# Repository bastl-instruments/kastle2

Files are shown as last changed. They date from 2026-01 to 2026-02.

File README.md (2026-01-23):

# Kastle 2

*Compatible with [Bastl Instruments Citadel](https://github.com/bastl-instruments/citadel)*

A modular DSP platform that fits into your pocket!  
Comes with open-source codebase (including two official firmwares) and schematics.

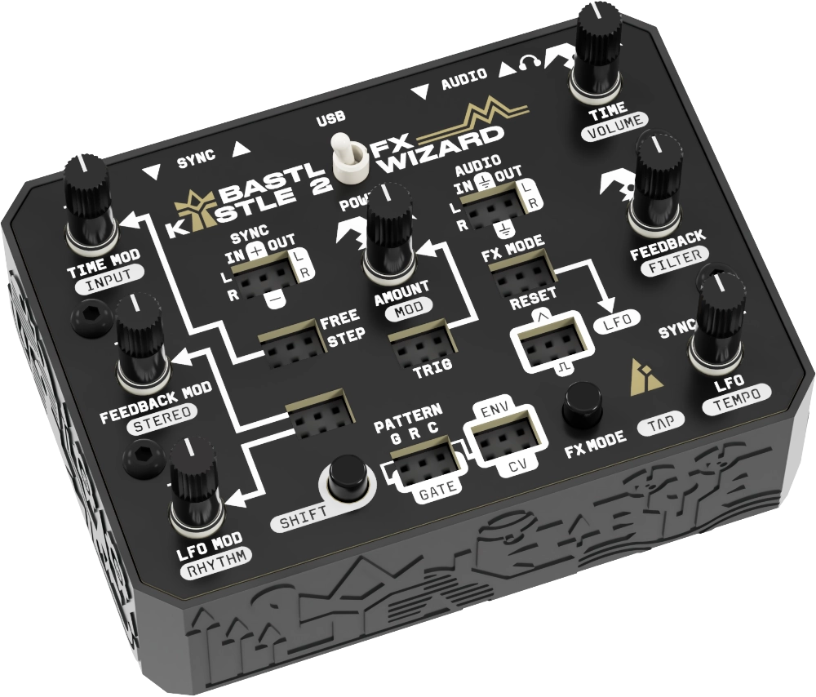
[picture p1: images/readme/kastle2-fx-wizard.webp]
Kastle 2
 

## How to develop for Kastle 2

Read [Toolchain Install Guide](TOOLCHAIN_INSTALL.md), [Coding Style Guide](CODING_STYLE.md) and [Glossary & Examples](GLOSSARY_EXAMPLES.md), or dive through the generated [Code Documentation](http://apps.bastl-instruments.com/kastle2-docs).
 
Any questions or weird stuff hapenning? See the [FAQ](FAQ.md) or discuss your experience on our [Discord server](https://discord.com/invite/C4RXRjgYJ6). 

## Specifications

- Raspberry Pi RP2040 MCU (264 kB RAM, clocked at 176 MHz)
- 8 MB flash for firmware and data
- 256 B EEPROM for storing calibration and settings
- 44kHz/16-bit stereo audio quality
- USB-C or 3xAA battery power (with automatic switching)
- 18 analog inputs (12-bit)
  - 2 direct inputs (sample rate > 1 kHz)
  - 16 multiplexed inputs (sample rate > 100 Hz)
- 3 digital inputs
- 3 analog outputs (using filtered 10-bit PWM)
- 3 digital outputs
- Stereo audio input (up to 6 Vpp)
- Stereo headphone output (suitable for up to 250 Ohm headphones)
- 3 RGB LEDs
- USB MIDI input & output - see the [MIDI Mappings](MIDI_MAPPINGS.md)

All inputs are designed to accept voltages in the range of 0-5V unless specified.  
All outputs are designed to provide 0-5V (0V to the input voltage, respectively).

## Connectivity
- USB-C (power, firmware updates, MIDI)
- Sync in jack (expects a clock signal at tip)
- Sync out jack (produces a clock signal at tip)
- Audio in jack
- Headphone out jack

## User interface
- 7 potentiometers
- 2 buttons
- Pin headers for patching
- Power switch

## Power consumption, battery life

Power consumption is approximately 100-150 mA, allowing for up to 15-18 hours of use on 3xAA batteries.

## Open Source Firmwares

The full firmware list is here: [app list](APP_LIST.md).

**FX Wizard**   
Nine time-based audio effects, with DJ-style lowpass/highpass filter.

**Wave Bard**   
Stereo sample player featuring unique sequencing techniques.

And other examples, see the `code/src/apps` subfolder.

## Useful links

**[Citadel repository](https://github.com/bastl-instruments/citadel)**  
A Eurorack adaptation of the Kastle 2 family. It's directly compatible with the Kastle 2 firmwares, there are no extra Citadel firmware builds. The firmware itself detects the variant it's running on (based on the MIDI pull-up resistor on RX line) and adjusts necessary parameters.

**[Kastle 2 Web Apps repository](https://github.com/bastl-instruments/kastle2-webapps)**  
Source codes for Wave Bard Sample Loader, Alchemist Laboratory…

**[Kastle 2 Label Maker repository](https://github.com/bastl-instruments/kastle2-labelmaker)**  
Source code for a tool which helps you visualize Kastle 2 app ideas.

## Credits

**Developed by**   
Václav Mach ([@xx0x](https://github.com/xx0x)), Marek Mach ([@machmar](https://github.com/machmar))

**Supervised by**  
Václav Peloušek ([@vaclav-bastl](https://github.com/vaclav-bastl)), Martin Klecl ([@martinklecl](https://github.com/martinklecl))

Thanks to Majkel ([@tenmajkl](https://github.com/tenmajkl)) with help around documentation and everyone at Bastl Instruments for their support while working on this!

## License

**Code**  
MIT license

**Schematics, Documentation, Templates, Printable 3D files**  
CC BY SA 4.0 license

**Voice recordings (Version, Calibration, Test Mode)**  
CC0 license, made using TTS Maker (voice 178 - Chloe) and sped up by 1.05x

**Panel graphics, Case artwork**  
All rights reserved

**Samples (eg. Wave Bard factory bank)**  
All rights reserved

*Note: You are welcome to create derived products based on the schematics and software. However, Bastl retains proprietary rights to the board layout, which is not publicly available. This prevents simple product cloning and maintains the integrity of the original Kastle 2. By purchasing an original Bastl Instruments Kastle 2 you support ongoing development.*

*Regarding samples: The SAMPLES.BIN file in the repository should not be commercially distributed as part of a custom-built firmware, nor separately, as it is marked “All rights reserved.” However, using the official compiled firmware provided by Bastl (which includes the samples) is fine.*

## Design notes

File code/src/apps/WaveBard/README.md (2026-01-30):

# Kastle 2 Wave Bard

Sample player firmware for the Kastle 2 platform. Has three main parameters: Sample, Pitch and Length.  
Bank button switches between banks.   
By default there are 6 banks of 8 samples.

## How to build

Running `make wave-bard` produces a firmware image with just the app itself—ideal for development or upgrade process.

Running `make wave-bard-with-samples` builds the app and appends the data from SAMPLES.bin, creating the complete firmware. That's the way the official firmwares are generated.

## Wave Bard Sample Format

The samples, scales and rhythms are packed in a special format. You can find the specs in the [WAVE_BARD_FORMAT.md](WAVE_BARD_FORMAT.md).

## SAMPLES.bin

Factory audio samples:  
Copyright (c) 2025 Oliver Torr for Bastl Instruments. All rights reserved.  

This file contains the factory default samples. You can generate a new file using Wave Bard Sample Loader with "Advanced" option on. In click on button labeled `GENERATE BIN` to download the binary file containing samples.

http://apps.bastl-instruments.com/wave-bard-sample-loader/?advanced=1

After swapping SAMPLES.bin make sure to call task `clean` to make a clean build, otherwise CMake might store previously generated output.

*Regarding samples: The SAMPLES.BIN file in the repository should not be commercially distributed as part of a custom-built firmware, nor separately, as it is marked “All rights reserved.” However, using the official compiled firmware provided by Bastl (which includes the samples) is fine.*

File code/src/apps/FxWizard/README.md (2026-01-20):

# Kastle 2 FX Wizard

Experimental effects firmware for the Kastle 2 platform with 9 unique effects. Has three main parameters: Time, Feedback and Amount (Dry & Wet and more).  

## FX Wizard File Format

You can use a specific format to load your custom rhythms into the FX Wizard. See the [FX_WIZARD_FILE_FORMAT.md](FX_WIZARD_FILE_FORMAT.md) for that or just use [FX Wizard Chamber](http://apps.bastl-instruments.com/fx-wizard-chamber) to get the current firmware with custom rhythms.

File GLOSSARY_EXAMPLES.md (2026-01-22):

# Kastle 2 Glossary & Examples

*See [Kastle 2 Code Documentation](http://apps.bastl-instruments.com/kastle2-docs) for the specific classes and methods.*

## App 

A complete firmware application that runs on your Kastle 2. Each app inherits from the virtual `App` base class and implements four core methods:

- `Init()` - setup resources, configure Base features
- `DeInit()` - cleanup and resource deallocation  
- `AudioLoop()` - real-time audio processing (marked with FASTCODE)
- `UiLoop()` - user interface, potentiometer readings, LED control

Apps have unique IDs for EEPROM persistence and automatic memory management. The main.cpp workflow follows this pattern:

```cpp
int main() {
    Kastle2::Init();
    Kastle2::RegisterApp(&app);
    app.Init();
    Kastle2::StartAudio(process_audio);
    
    while (true) {
        Kastle2::ReadInputs();
        app.UiLoop();
    }
}
```

Optional methods include `SecondCoreWorker()` for dual-core processing, `MidiCallback()` for MIDI handling, and `MemoryInitialization()` for first-time setup. Examples include FxWizard (effects processor), WaveBard (sample player), ExampleSynth (simple synthesizer), Calibration (pitch input V/Oct calibration) and Template (to start projects from scratch).

## Base

Essential foundation layer that provides core functionality for all Kastle 2 firmware applications. Manages hardware abstraction including input/output volumes, LFO generation, sequencer with multiple rhythm patterns, clock with sync capabilities, layer switching (normal/shift/mode), and CV/Gate outputs.

Features can be selectively disabled for custom control:

```cpp
// Common feature disabling examples
Kastle2::base.SetFeatureEnabled(Base::Feature::AUDIO_CHAIN, false);  // Handle mixing manually
Kastle2::base.SetFeatureEnabled(Base::Feature::ENV_OUT, false);      // Disable envelope follower output, control the pin directly
Kastle2::base.SetFeatureEnabled(Base::Feature::LFO_OUT, false);      // Use LFO pins for custom purposes
```

Provides three critical audio processing hooks: `BeforeAudioLoop()` (handles input gain, LFO/clock stepping), the app's AudioLoop(), and `AfterAudioLoop()` (applies output gain, audio chain mixing).

Access subsystems through dedicated getters for advanced control:

```cpp
Kastle2::base.GetSequencer().SetLength(16);
Kastle2::base.GetLfo().SetFrequency(2.5f);
Kastle2::base.GetClock().IsNowTrigger();
```

## CV and Digital IO

**Reading inputs:**
- **CV inputs**: Range 0-4095 representing 0-5V on Kastle 2 (can be -4095 to +5733 on Citadel meaning -5V to +7V range)
- **Digital inputs**: Boolean values (true/false)
- **Dual inputs**: `TRIG_IN` and `RESET` can be read both as analog CV (0-4095) and digital trigger (true/false)

**Writing outputs:**
- **CV outputs**: Range 0-1023 representing percentage of available voltage (depends on power source)
- **Digital outputs**: Boolean values, ones and zeros

```cpp
// Read CV inputs (0-4095 = 0-5V)
int32_t pitch_cv = Kastle2::hw.GetAnalogValue(Hardware::AnalogInput::PITCH_1);
int32_t param_cv = Kastle2::hw.GetAnalogValue(Hardware::AnalogInput::PARAM_1);

// Read digital inputs
bool trigger_in = Kastle2::hw.GetDigitalIn(Hardware::DigitalInput::TRIG_IN);
bool reset_in = Kastle2::hw.GetDigitalIn(Hardware::DigitalInput::RESET_IN);
bool trigger_in2 = Kastle2::hw.GetTrigIn();  // Shorthand for TRIG_IN

// Dual inputs - can be read both analog and digital
int32_t trigger_cv = Kastle2::hw.GetAnalogValue(Hardware::AnalogInput::TRIG_IN); 
int32_t reset_cv = Kastle2::hw.GetAnalogValue(Hardware::AnalogInput::RESET);     

// Write digital outputs
Kastle2::hw.SetGateOut(true); // Send gate signal
Kastle2::hw.SetDigitalOut(Hardware::DigitalOutput::SYNC_OUT, false);

// Write analog outputs (0-1023 as percentage of max voltage)
Kastle2::hw.SetAnalogOut(Hardware::AnalogOutput::ENV_OUT, 512);  // ~50% of max voltage
```

*Note: Analog output voltage depends on power source (3×AA batteries vs USB), so use values as percentages rather than absolute voltages.*

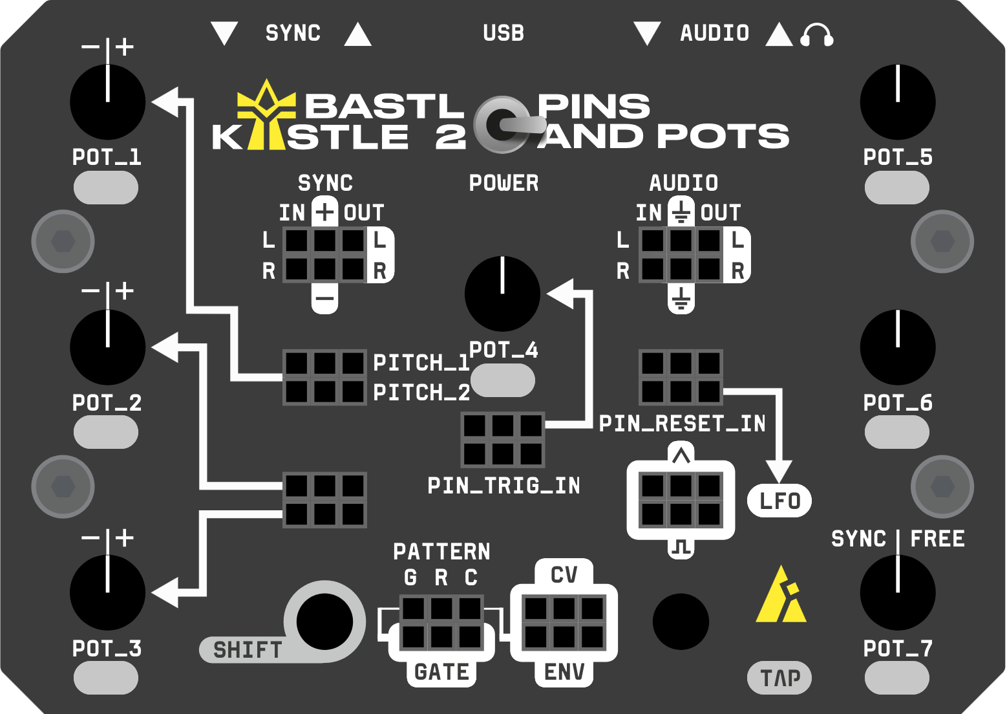
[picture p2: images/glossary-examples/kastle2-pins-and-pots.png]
Layout of pins and pots
 

## Debug Pins

Debug pins provide hardware-level performance monitoring and debugging capabilities. The primary debug pin is exposed as TX (GPIO0) and is commonly used to monitor audio loop performance timing when `MEASURE_AUDIO_LOOP` is enabled in the config file.

```cpp
// Toggle debug pin for performance measurement
Kastle2::hw.SetDebugPin(0, 1);  // Set pin high
// ... code to measure ...
Kastle2::hw.SetDebugPin(0, 0);  // Set pin low
```

A second debug pin (GPIO1/RX) is available but requires disabling UART MIDI functionality since the pin is primarily used for the MIDI input.

## DSP and Utilities

The Kastle 2 source code includes a comprehensive collection of DSP classes and utility functions for audio processing, synthesis, effects, and control. The classes are specifically optimized for the fixed-point arithmetic system.

**Common DSP classes include:**
- **Synthesis**: Oscillator, MultiOutOscillator...
- **Filters**: Svf, DjFilter...
- **Effects**: BitCrusher, StereoDelay, SoftClipper, HardClipper...
- **Control**: AdsrEnv , EnvelopeFollower...
- **Sampling**: SamplePlayer...
- **Utilities**: Quantizer, AutoFreeze, Portamento...

Most DSP classes follow a standard pattern with `Init(sample_rate)` for setup and `Process()` methods for real-time audio processing. All audio processing functions are marked with `FASTCODE` for optimal performance and use Q15/Q31 fixed-point arithmetic throughout.

## EnumArray&lt;T&gt;

A safe and efficient enum-indexed array template class that allows using enum values as array indices. The enum must have a `COUNT` value to determine the size of the array. Provides type-safe array access using enum values instead of raw integers, making code more readable and preventing indexing errors.

```cpp
enum class Mode { DELAY, FLANGER, CRUSHER, COUNT };

// Declaration with initialization
EnumArray<Mode, uint32_t> led_colors = {
    WS2812::GREEN,    // Mode::DELAY
    WS2812::CYAN,     // Mode::FLANGER  
    WS2812::YELLOW    // Mode::CRUSHER
};

// Safe access using enum values
led_colors[Mode::DELAY] = WS2812::RED;

// Iterate directly through the array
for (auto &color : led_colors) {
    ProcessColor(color);
}

// Iterate through all enum values with EnumRange
for (Mode mode : EnumRange<Mode>()) {
    IndicateMode(mode);
}

// Cycle through enum values with EnumIncrement
Mode current_mode = Mode::DELAY;
current_mode = EnumIncrement(current_mode);  // Now Mode::FLANGER
```

## DirtyInputsHandler

Template class for handling ADC inputs where you need to be 100% sure they have the latest values (usually for sample & hold operations). When triggered, it flags specified analog inputs as "dirty" forcing fresh ADC reads, then waits until all inputs have been refreshed before allowing the trigger to proceed. Essential for time-critical operations where stale ADC values could cause audio artifacts and inconsistent sequences.

## FancyMode

High-level abstraction for mode switching with advanced features including MIDI support, memory saving/loading, CV control with attenuating, and smart mode change prevention when tweaking parameters while holding MODE button.

Key features:
- **Multi-source input**: Can read value based on button presses or MIDI sources (CCs, notes)
- **Handles modulation**: CV input with configurable attenuator for voltage control
- **Memory persistence**: Automatically saves/restores values from EEPROM

```cpp
// Declaration with configuration
FancyMode mode_selector_ = FancyMode(FancyMode::Config{
    .memory_addr = kMemMode,
    .modes_count = static_cast<size_t>(Mode::COUNT),
    .midi_cc = cc::MODE,
    .adc_input = Hardware::AnalogInput::MODE
});

// In Init()
mode_selector_.Init(static_cast<size_t>(Mode::COUNT));

// Call in AudioLoop() for proper timing
mode_selector_.Process();

// Call in UiLoop() to read inputs  
mode_selector_.ReadValue();
uint32_t current_mode = mode_selector_.GetMode();
```

## FancyPot

Advanced potentiometer control class that provides MIDI integration, memory persistence, movement detection, and multi-layer support.

Key features:
- **Multi-source input**: Can read values from physical pots or MIDI sources (CCs, notes)
- **Movement detection**: Distinguishes between small tweaks vs large parameter changes
- **Memory persistence**: Automatically saves/restores values from EEPROM
- **Layer support**: Reads the pot only if a specific layer is selected

```cpp
// Declaration with configuration
std::unique_ptr<FancyPot> feedback_pot_ = FancyPot::Create({
    .pot = Hardware::Pot::POT_2,
    .layer = Hardware::Layer::SHIFT,
    .initial_value = pot(0.75f),  // 75% using compile time constructor
    .midi_cc = cc::FEEDBACK,
    .deadzone = true, // Center deadzone (pots aren't ideal)
    .freeze = true,    // Useful for filtering out noise
    .memory_addr = kMemFeedback
    // ...     
});

// In Init()
feedback_pot_->Init(AUDIO_LOOP_RATE);

// Call in AudioLoop() for proper timing
feedback_pot_->Process();

// Call in UiLoop() to read pot/MIDI values
feedback_pot_->ReadValue();
if (feedback_pot_->HasChanged()) {
    // Receive value in 0-4095 range
    int32_t feedback_value = feedback_pot_->GetValue();
}
```

## FASTCODE

A compiler attribute that marks functions to be placed in a special `.fastcode` section in the binary. This code is copied from external QSPI flash to RAM at startup for speed improvements. Running code from RAM also prevents unpredictable caching behavior that can occur when pushing the chip to its performance limits, ensuring consistent timing for real-time audio processing.

The fastcode section is limited to 16 kB due to the RP2040's constrained RAM space, use it only for functions which need crucial timings.

## map

Core mapping function that transforms values from one range to another with linear scaling, similar to Arduino's `map()` function but with advanced safety features. Can map between different numeric types (int, float, etc.) with automatic type promotion.

Supports two important safety modes:
- **MapSafe** - uses 64-bit math to prevent integer overflow for large numbers (ignored for floating-point types); slower than the default 32-bit but necessary for Q31 computations
- **MapClamp** - constrains output to target range vs allowing extrapolation

```cpp
// Basic usage: map pot value (0-4095) to frequency (20-20000 Hz)
float freq = map(pot_value, 0, 4095, 20.0f, 20000.0f);

// With safety features
int32_t safe_result = map(large_value, 0, 1000000, 0, 32767, MapClamp::TRUE, MapSafe::TRUE);
```

## MapDef&lt;T, N&gt;, curve_map()

**MapDef** is a compile-time mapping table template that stores input and output value arrays for creating custom parameter curves. Used with **curve_map()**, **enum_map()** and **step_map()** functions to perform linear interpolation between defined points, enabling complex response curves like exponential, logarithmic, or custom shapes while maintaining efficient performance.

Unlike the basic `map()` function, `curve_map()` and others support non-linear mappings by interpolating between user-defined breakpoints:

```cpp
// Define a custom distortion curve
static constexpr auto kMapDistortionAmount = MapDef<int32_t, 5>{
    {pot(0.0f), pot(0.55f), pot(0.85f), pot(0.95f), pot(1.0f)},  // Input breakpoints
    {q15(0.0f), q15(0.0f), q15(0.04f), q15(0.25f), q15(0.6f)}   // Output values
};

// Apply the curve mapping
q15_t distortion = curve_map(pot_value, kMapDistortionAmount);
```

## q15_t, q31_t, q31_add(), q15_mult()...

Since the RP2040 lacks a dedicated FPU (floating-point unit), float operations are slow due to software emulation. To maximize performance, we use a fixed-point arithmetic system wherever possible, representing values from -1.0 to +1.0. This approach enables relatively complex DSP functionality on the RP2040 microcontroller, even with its limited hardware resources.

**Q15 format**: 1.15 format (1 sign bit, 15 fractional bits) for simpler calculations (eg. filter)  
**Q31 format**: 1.31 format (1 sign bit, 31 fractional bits) for higher precision calculations (eg. envelope)

Common operations include:

```cpp
q15_t gain = q15(0.5f);                       // Compile-time constructor
q15_t result = q15_mult(signal, gain);        // Multiplication with saturation
q15_t sum = q15_add(left, right);             // Addition with overflow protection  
q15_t safe = q15_saturate(large_value);       // Clamp to valid range
q31_t precise = q15_to_q31(q15_value);        // Format conversion
```

**Performance optimization**: Fixed-point arithmetic requires calculations in double bit-width (16-bit Q15 operations need 32-bit intermediate results, while 32-bit Q31 operations need 64-bit intermediates). This is why Q15 is preferred over Q31 on the RP2040 - it stays within efficient 32-bit math.

Q15 values are stored as `q15_t` (32-bit) rather than native 16-bit to avoid memory padding overhead on the RP2040's 32-bit ARM architecture. When the compiler stores 16-bit values, it must pad them to 32-bit boundaries during calculations, which takes extra CPU cycles.

When memory conservation is critical (e.g., large delay lines), use `q15least_t` for actual 16-bit storage. This design provides the ideal balance between computational efficiency and memory usage for real-time audio processing.

*Note: We tested the official ARM CMSIS-DSP library and in real usage it was slower than our custom implementation.*

## ShiftTrigger

Utility function that detects when the SHIFT button was quickly pressed and released (short press). Returns `true` when the previous layer was SHIFT, current layer is NORMAL, and the layer timer is less than the short press threshold. It works in symbiosis with FancyPot and layer switching - quick triggers and turning eg. Sample Pot on WaveBard won't change the Filter.

```cpp
void AppExample::UiLoop() {
    // Check for quick SHIFT press to trigger an action
    if (ShiftTrigger()) {
        // Perform quick action (e.g., tap tempo, reset parameter, etc.)
        TriggerEnvelope();
    }
    
    // Normal layer handling
    if (Kastle2::hw.GetLayer() == Hardware::Layer::SHIFT) {
        // SHIFT is held down - show alternate UI, different parameters
        ShowShiftLayerUi();
    } else {
        // Normal layer operation
        ShowNormalUi();
    }
}
```

## Test Mode

Diagnostic and testing system incorporated into every Kastle 2 firmware. Users can enter test mode by holding the MODE button during startup. At the beginning the current firmware version is announced. Then the test mode runs automated tests that verify hardware functionality, including audio I/O, potentiometer readings, button responses and patchbay (see image below for the wiring). The test results are continously outputed using UART over USB (baud rate 115200).

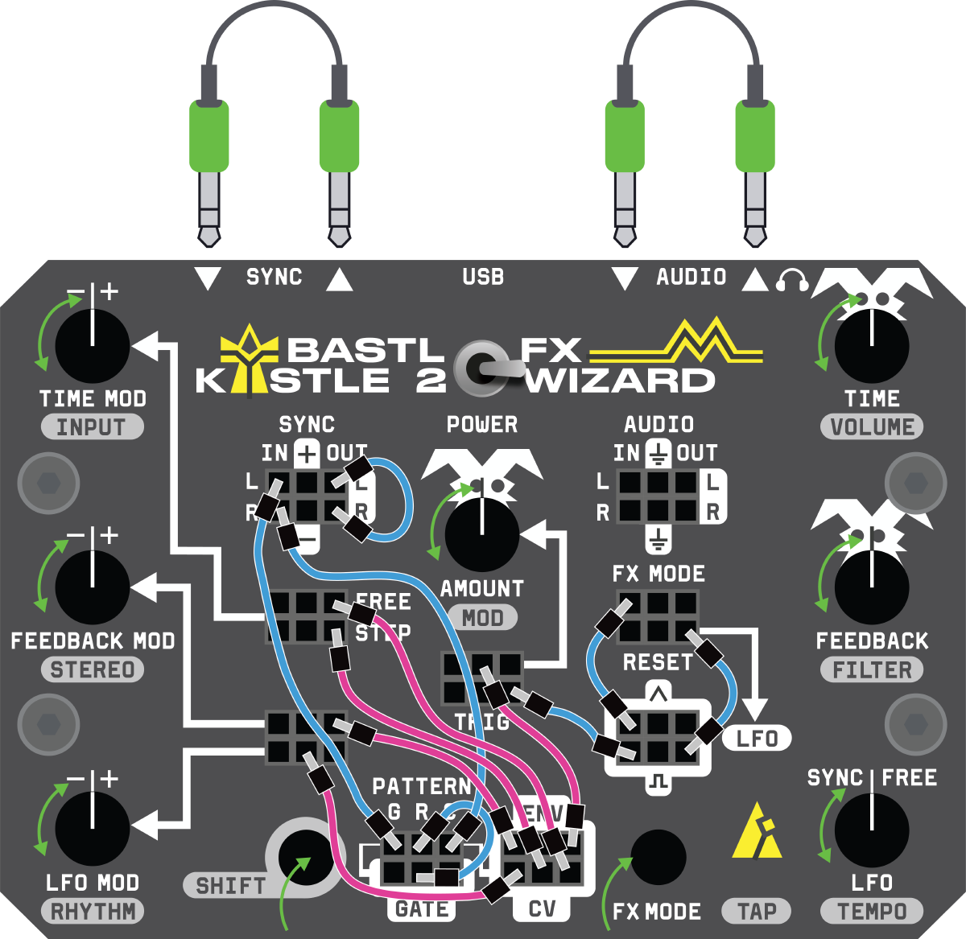
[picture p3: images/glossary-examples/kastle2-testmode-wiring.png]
Kastle 2 Test Mode wiring to pass the test
 

## Universal Firmware (Kastle 2 / Citadel)

Starting with firmware version 1.5, we added Citadel support to existing Kastle 2 releases. Having a single firmware release greatly simplifies testing, maintenance, and communication—saving us considerable time and effort. While the core functionality remains identical between the two devices, the ADC mappings and calibrations differ because the Citadel features an expanded CV input range. 

When developing the code, most of the time you don't need to care if your app runs on Kastle 2 or Citadel. In case you'd need to know it, there is a function for that.

```cpp
auto version = Kastle2::hw.GetVersion();
// returns either Hardware::Version::KASTLE2 or Hardware::Version::CITADEL
```

Due to the limited number of I/O pins, we chose to reuse the TRS MIDI RX pull-up resistor for device detection. This approach effectively solved the auto-detection challenge, but it comes with one limitation:
**you cannot retrofit an existing Kastle 2 with MIDI support while using the official Kastle 2 firmwares**, as doing so would cause the input mappings to be incorrect. If you want to use TRS MIDI alongside a 0–5V CV system, you’ll need to adapt your schematic to correctly invert and shift the analog input levels. Or compile your custom firmware with the usage of `Hardware::ForceVersion()` method.

## VersionChainGenerator

Compile-time utility class that generates audio sample chains from version strings for the test mode. Translates version strings like "1.2" into arrays of audio samples like ["app_name", "version", "one", "point", "two"]. Uses template metaprogramming to build the sample chain at compile time, enabling the device to speak its version number and app name during testing and diagnostics.

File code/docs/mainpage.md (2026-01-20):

# Kastle 2

A modular DSP platform that fits into your pocket!

Kastle 2 is an open-source codebase embedded audio processing platform built on the Raspberry Pi RP2040 MCU using the official Pico SDK.

## Project Overview

- **Platform**: Raspberry Pi RP2040 (ARM Cortex-M0+ dual-core)
- **Memory**: 264 kB RAM, 8 MB flash storage
- **Audio**: 44kHz/16-bit stereo processing
- **I/O**: 18 analog inputs, 3 digital inputs, 3 analog outputs, 3 digital outputs
- **Connectivity**: USB-C, MIDI, audio I/O, sync I/O

## Development Resources

For comprehensive development information, visit the [Kastle 2 GitHub repository](https://github.com/bastl-instruments/kastle2/).

### Guides
- [Toolchain Installation](https://github.com/bastl-instruments/kastle2/blob/main/TOOLCHAIN_INSTALL.md) - Set up your development environment
- [Coding Style Guide](https://github.com/bastl-instruments/kastle2/blob/main/CODING_STYLE.md) - Project coding standards
- [Glossary & Examples](https://github.com/bastl-instruments/kastle2/blob/main/GLOSSARY_EXAMPLES.md) - Key concepts and code examples
- [FAQ](https://github.com/bastl-instruments/kastle2/blob/main/FAQ.md) - Common development issues
- [Application List](https://github.com/bastl-instruments/kastle2/blob/main/APP_LIST.md) - Overview of all available firmwares
- [MIDI Mappings](https://github.com/bastl-instruments/kastle2/blob/main/MIDI_MAPPINGS.md) - MIDI implementation details

## Architecture

The codebase is organized into several key components:

- **DSP Engine**: Real-time audio processing algorithms
- **Hardware Abstraction**: RP2040-specific peripheral drivers  
- **Application Framework**: Common functionality shared across firmwares
- **User Interface**: Knobs, buttons, LEDs
- **MIDI/USB**: Communication protocols

## License

- **Code**: MIT License
- **Schematics/Documentation**: CC BY SA 4.0
- **Panel graphics/Case artwork/Samples**: All rights reserved

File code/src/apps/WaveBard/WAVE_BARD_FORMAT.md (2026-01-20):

# Wave Bard Sample Format

The Wave Bard binary format is a file with a maximum size of 7.5 MB, located at RP2040 memory address 0x10080000. It contains raw signed 16-bit audio samples, without WAV header. It follows the application space, which begins at 0x10000000 and spans 512 kB. To ensure precise alignment, the Wave Bard firmware is padded with zeros to exactly 512 kB before appending this binary file. Finally, the combined data is converted into the UF2 format using a Python script.

_Sections are 4-byte aligned to work with the ARM CPU memory layout._

| Field | Value | Size (bytes) |
| --- | --- | --- |
| **Main Header** | | **20** |
| Magic String | "k2wb" | 4 |
| File Size | Total file size (including "end") | 4 |
| Sample Rate | eg. 44100 | 4 |
| Bit Depth | only 16 is now supported | 1 |
| Num Banks | usually 1 to 9 | 1 |
| Num Samples | usually 8 | 1 |
| Num Scales | usually 7 | 1 |
| Num Rhythms | usually 16 | 1 |
| Sequencer Length  | usually 16 | 1 |
| Reserved | | 1 |
| Reserved | | 1 |
| **Scales** | LSB First (12 bits) | **28?** |
| Minor Chord | 0b000010001001 | 4 |
| Minor Pentatonic  | 0b101010110101 | 4 |
| Minor Diatonic | 0b010110101101 | 4 |
| Chromatic | 0b111111111111 | 4 |
| Major Diatonic | 0b101010110101 | 4 |
| Major Pentatonic  | 0b001010010101 | 4 |
| Major Chord | 0b000010010001 | 4 |
| **Rhythms** | MSB first (16 bits) | **64?** |
| Rhythm 1 | 0b1000000010000000 | 4 |
| Rhythm 2 | 0b1000100010001000 | 4 |
| Rhythm 3 | 0b1000101010001010 | 4 |
| Rhythm 4 | 0b1000001001001000 | 4 |
| Rhythm 5 | 0b1000000000100000 | 4 |
| Rhythm 6 | 0b1010000110100000 | 4 |
| Rhythm 7 | 0b1000100000101000 | 4 |
| Rhythm 8 | 0b1000100010010010 | 4 |
| Rhythm 9 | 0b0010001000100010 | 4 |
| Rhythm 10 | 0b0010010001000110 | 4 |
| Rhythm 11 | 0b0010001000110010 | 4 |
| Rhythm 12 | 0b1111101010111010 | 4 |
| Rhythm 13 | 0b0000111100001100 | 4 |
| Rhythm 14 | 0b1010110010101100 | 4 |
| Rhythm 15 | 0b0011001100110010 | 4 |
| Rhythm 16 | 0b0111011101110111 | 4 |
| **Bank Header 1** | | **12** |
| Name | "bank1111" | 8 |
| Color R | 0-255 | 1 |
| Color G | 0-255 | 1 |
| Color B | 0-255 | 1 |
| Reserved | | 1 |
| **Sample 1** | | **16-??** |
| Sample Size | eg. 22050 (means 11025 16-bit samples) | 4 |
| Sample Channels | 1 or 2 | 1 |
| Sample Name | "sample01" | 8 |
| Reserved | | 1 |
| Reserved | | 1 |
| Reserved | | 1 |
| Sample Data | Audio data | eg. 22050 |
| **Sample 2** | | **16-??** |
| Sample Size | eg. 22050 (means 11025 16-bit samples) | 4 |
| Sample Channels | 1 or 2 | 1 |
| Sample Name | "sample02" | 8 |
| Reserved | | 1 |
| Reserved | | 1 |
| Reserved | | 1 |
| Sample Data | Audio data | eg. 22050 |
| **Bank Header 2** | | **12** |
| Name | "bank2222" | 8 |
| Color R | 0-255 | 1 |
| Color G | 0-255 | 1 |
| Color B | 0-255 | 1 |
| Reserved | | 1 |
| **Sample 1** | | **16-??** |
| Sample Size | eg. 22050 (means 11025 16-bit samples) | 4 |
| Sample Channels | 1 or 2 | 1 |
| Sample Name | "sample01" | 8 |
| Reserved | | 1 |
| Reserved | | 1 |
| Reserved | | 1 |
| Sample Data | Audio data | eg. 22050 |
| **End Marker** | | **4** |
| End Marker | "ahoj" | 4 |

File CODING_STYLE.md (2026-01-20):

# Kastle 2 Coding Style Guide
This document outlines the coding style conventions to be followed for the Kastle 2 project. Adhering to these guidelines will ensure consistency and readability across the project's codebase.

## 1. C++ Header Files
Use `#pragma once` at the beginning instead of old-style include guards.
Header files should have `*.hpp` extension.

```cpp
MyClassName.hpp

#pragma once
```

## 2. Class Names
Class names should be written in **PascalCase**. This means that the first letter of each word in the class name should be capitalized, with no spaces, underscores, or other separators between the words.

**Example:**

```cpp
class MyClassName {
    // Class implementation
};
```

## 3. Method Names
Method names should be written in **PascalCase**. This means that the first letter of each word in the method name should be capitalized, with no spaces, underscores, or other separators between the words.

**Example:**

```cpp
bool MyMethodName(bool parameter) {
    // Method implementation
}
```

## 4. Local variables
Local variables should be written in lowercase, with words separated by underscores (_).

**Example:**

```cpp
int32_t a_very_nice_number;
```

## 5. Private Member Variables
Private member variables should be written in **lowercase**, with words separated by underscores (_), and should include a trailing underscore.

**Example:**

```cpp
private:
    float a_very_nice_number_;
    q31_t amplitude_;
    q31_t phase_, phase_inc_;
```

## 6. Constants
Constants should be named starting a lowercase **k**, then **PascalCase**.

**Example:**

```cpp
static constexpr int32_t kImportantNumber = 69420;
static const auto kMapRingMod = MapDef<int32_t, 4>{
    {pot(0.0f), pot(0.4f), pot(0.7f), pot(1.0f)},
    {q15(0.0f), q15(1.0f),q15(1.0f), q15(4.0f)}};

```

## 7. Enums
Enumerations should be used to define a set of named integer constants. The enum name should be singular if we presume only one entry is valid at once. Enumerator names should be written in uppercase, with the last item in the enumeration representing the total count of enumerators. Use `enum class` instead of plain enums. With this structure you can then use utilities like EnumArray or EnumIncrement.

**Example:**

```cpp
enum class MyBerry
{
    RASPBERRY,        
    BLUEBERRY, 
    STRAWBERRY,
    COUNT 
};

EnumArray<MyBerry, int32_t> berries_count;

MyBerry current_berry = MyBerry::RASPBERRY;
current_berry = EnumIncrement(current_berry);
```

## 8. Code Formatting
Use 4 spaces for indentation; do not use tabs. Always include braces for `if`, `for`, `while`, and other control statements.
Don't put control statements and their code blocks on the same line.

**Example:**

```
if (condition)
{
    OneLineFunction();
}
```

## 9. Miscellaneous
Use `constexpr` and `const` where applicable, especially for parameters and values that should not be modified.
Prefer meaningful variable names over single-letter names, except in loop counters where i, j, etc., are acceptable.

By adhering to these guidelines, the Kastle 2 project will maintain a high standard of code quality and readability. These conventions will make it easier for developers to collaborate and maintain the codebase over time.

Thank you and happy coding!

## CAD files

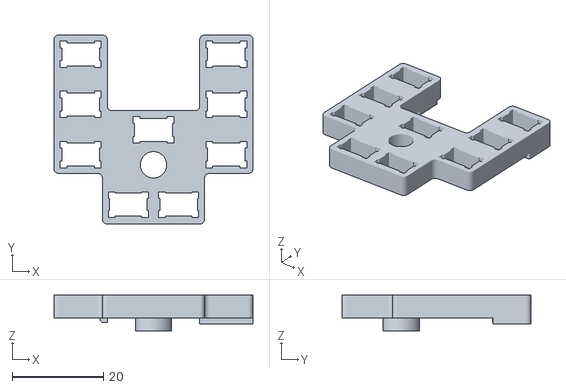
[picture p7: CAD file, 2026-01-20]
case/stl/kastle2-pinheaders-holder.stl
43.7 x 41.5 x 7.90

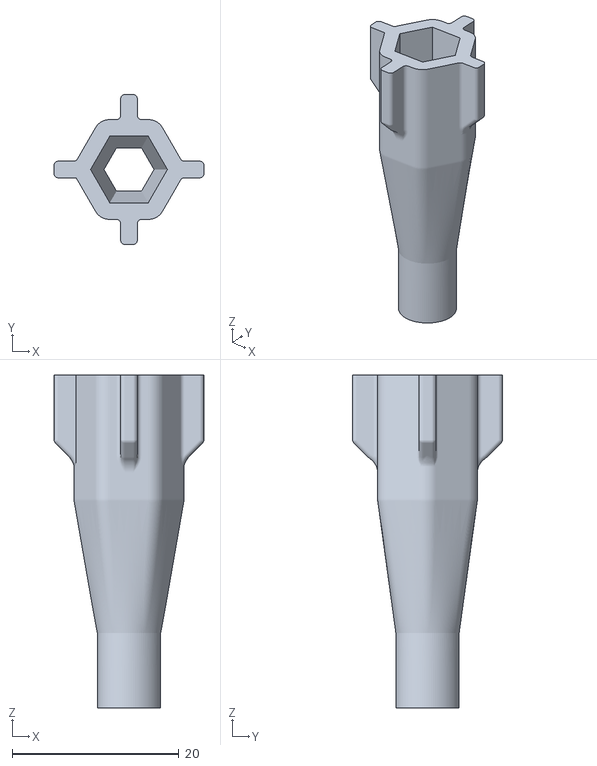
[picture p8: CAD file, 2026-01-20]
case/tools/kastle2-socket-driver.stl
18.0 x 18.0 x 40.0

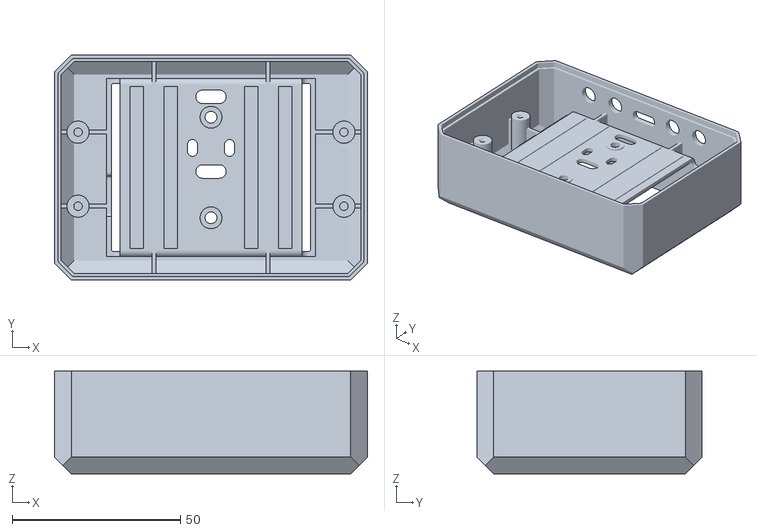
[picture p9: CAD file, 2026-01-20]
case/stl/kastle2-case-nographics-noinserts.stl
93.0 x 67.0 x 30.6

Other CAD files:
case/stl/kastle2-case-nographics.stl
case/stl/kastle2-case-nographics-noinserts-programming.stl
case/stl/kastle2-case-nographics-programming.stl

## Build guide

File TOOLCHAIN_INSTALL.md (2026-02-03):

# Kastle 2 Toolchain Install Guide

## Introduction

You need to install GIT, Python 3, CMake, GNU Embedded Toolchain for ARM, Picotool (optional) and Doxygen (optional). For the development itself we recommend using VS Code, but you can use any editor/environment you like.

For beginners, we recommend the [Automated Install](#automated-install-nix); for advanced users who regularly develop for ARM, we recommend the [Manual Install](#manual-install).

## Clone the GitHub repository

The starting point for both installation methods.

```
git clone https://github.com/bastl-instruments/kastle2.git
```

## Automated Install (Nix)

The easiest way to get started is with Nix — an isolated development environment that automatically installs all the requirements. It runs natively on macOS/Linux and won't interfere with your existing system tools. Thanks very much to [@euphemism](https://github.com/euphemism) for creating the Nix‑based development setup.

### Nix install
Make sure Nix is installed (check with `nix --version`). If it's not, install it from the [official website](https://nixos.org/download/).  
Enable Flakes by adding this line to `~/.config/nix/nix.conf`:
```
experimental-features = nix-command flakes
```

### Using the Nix shell

Go into the `kastle2` folder and start the Nix development environment. The first setup may take a few minutes, subsequent shells are fast.
```
nix develop .#
```
This shell automatically runs `./configure.sh` on first use (when the build folder doesn't exist).  
Go into `code/build` and run `make` to build all firmwares or `make <app-name>` to build a specific one.  
Launch your editor from within the Nix shell so it inherits the environment variables.

```
cd code/build

make wave-bard
make wave-bard-with-samples

code
```

You can find the compiled firmwares inside `code/build/output`.  
If you successfully installed the Kastle 2 Development shell, jump to the [Debugging section](#debugging) to continue.

## Manual Install

If you have already ARM Toolchain installed make sure it's version `14.2.1 20241119` or above by running:
```
arm-none-eabi-gcc --version
```

In case you have more than one ARM Toolchains installed (eg. you are using Daisy Toolchain), you can run this to get the specific one for the Raspberry Pi Pico platform:
```
$PICO_TOOLCHAIN_PATH/arm-none-eabi-gcc --version
```

#### MacOS (brew)

Make sure you have [Homebrew](https://brew.sh/) installed.
Then run these.

```
brew install cmake git python picotool doxygen
brew install --cask gcc-arm-embedded
```

If `gcc-arm-embedded` install through brew fails, download the ARM Toolchain manually from the [official ARM website](https://developer.arm.com/downloads/-/arm-gnu-toolchain-downloads). Select the `arm-none-eabi` and your platform (macOS x86_64, macOS Apple sillicon). Download the archive, extract it eg to `/Users/username/arm_kastle`. Then add this into `~/.zshrc`:
```
export PICO_TOOLCHAIN_PATH=/Users/username/arm_kastle/bin
```

#### Linux (apt – Ubuntu/Debian)

```
sudo apt update
sudo apt install git cmake gcc-arm-none-eabi libnewlib-arm-none-eabi build-essential libstdc++-arm-none-eabi-newlib doxygen
```

If you want to upload the code automatically using USB, download and build `picotool` using this tutorial:  https://github.com/raspberrypi/picotool You can find a detailed tutorial how to build it in [Getting started with Pico](https://datasheets.raspberrypi.com/pico/getting-started-with-pico.pdf) document, around page 25.

After installing the packages, make sure that the ARM compiler is the required version or later, as described [in the "Manual Install" section](#manual-install) above.
If you are running Ubuntu, you need to be on the version 25.04 (Plucky Puffin) or later to get the correct one. If upgrading a WSL Ubuntu install, it may be necessary to [remove the `snapd` package](https://askubuntu.com/questions/1428423/upgrade-ubuntu-in-wsl2-from-20-04-to-22-04) before upgrading. 

#### Linux (pacman – Arch)

```
sudo pacman -Syu
sudo pacman -S git cmake arm-none-eabi-gcc arm-none-eabi-newlib doxygen
```

#### Windows

The easiest way is to follow the [Raspberry Pi Pico-series guide](https://datasheets.raspberrypi.com/pico/getting-started-with-pico.pdf).

### Get the Raspberry Pi Pico SDK

This applies to MacOS and Linux installations.

Kastle 2 is compatible both with the original Pico SDK 1.x and new 2.x. We strongly recommend to use the latest 2.x release to make sure everything works.
Navigate to a folder you want the SDK to be downloaded and clone the repository:

```
git clone https://github.com/raspberrypi/pico-sdk.git
```

Inside this folder, run this command in order to download additional libraries.

```
git submodule update --init
```

In your environment set PICO_SDK_PATH to the SDK location.

#### Linux

Add this line into `~/.bashrc`. Tilde symbol `~` is your user's home directory. If the file doesn't exist, create it.
```
export PICO_SDK_PATH=/path/to/your/pico-sdk
```

#### Mac OS
Add this line into `~/.zshrc`. Tilde symbol `~` is your user's home directory. If the file doesn't exist, create it.
```
export PICO_SDK_PATH=/path/to/your/pico-sdk
```

### Configure and compile it

#### VS Code

If you used VS Code for editing `.zshrc` or `.bashrc` file, restart it for the `export` to make effect.

Open the whole project folder (not just `code` subfolder) and run task called `configure`. Or use CMake extension to configure it. Then you can run `build_and_upload_usb` to upload the code into Kastle 2 via USB. If the USB upload doesn't work, turn off the Kastle 2 and hold SHIFT and power it on to enter the bootloader mode. Or use `build_and_upload_jlink` for J-Link upload. See section below for the available debuggers.

#### Or run configure.sh
```
./configure.sh
```
#### Or manually run this
```
mkdir code/build
cd code/build
cmake -DCMAKE_BUILD_TYPE=Debug ..
make
```
And then copy `code/build/output/kastle2-xxxx.uf2` manually onto the Kastle 2 mounted as USB drive.

If you want to compile just a single project, just type in `make template` or `make wave-bard`.

## Debug vs Release builds

At Bastl we use the `-O3` optimization flag even for Debug builds, because we can't run the existing code without optimizations. The builds also include `-g` for debug symbols. Since our development and testing time is limited, we usually don't bother recompiling the code using the Release flag, because we would need to retest every feature and sound signature all over again to make sure everything runs correctly.

## Debugging

Real-time code stepping and debugging is possible while the code is being executed. For that, Kastle 2 needs to be connected via SWD interface (SWDIO, SWCLK...) on the bottom side of the PCB. For each debug pin the PCB contains two locations to choose from (only one needs to be connected). This method also lets you upload firmware faster than UF2 method using USB.

We have predefined profiles for the [Raspberry Pi Debug Probe](https://www.raspberrypi.com/documentation/microcontrollers/debug-probe.html) and [Segger J-Link](https://www.segger.com/products/debug-probes/j-link/models/j-link-base/). In case you have an experience with other probes, feel free to write us with your experience and we can add it to the list.

If you don't have any probe and you have a Raspberry Pi Pico laying around, you can make your own probe using it. You can follow eg. [this tutorial](https://www.youtube.com/watch?v=0i2gLeBal9Y).

### Connections

Solder cable to the pins depending on your platform.

> [!WARNING]
> Soldering the connector and other board modification void the official warranty and you do it at your own risk.

**Raspberry Pi Debug Probe** requires: SWDIO, SWCLK, GND.  
**Segger J-Link Debug Probe** requires: SWDIO, SWCLK, GND, VDD, RESET.

#### This image shows the Raspberry Pi Debug Probe:

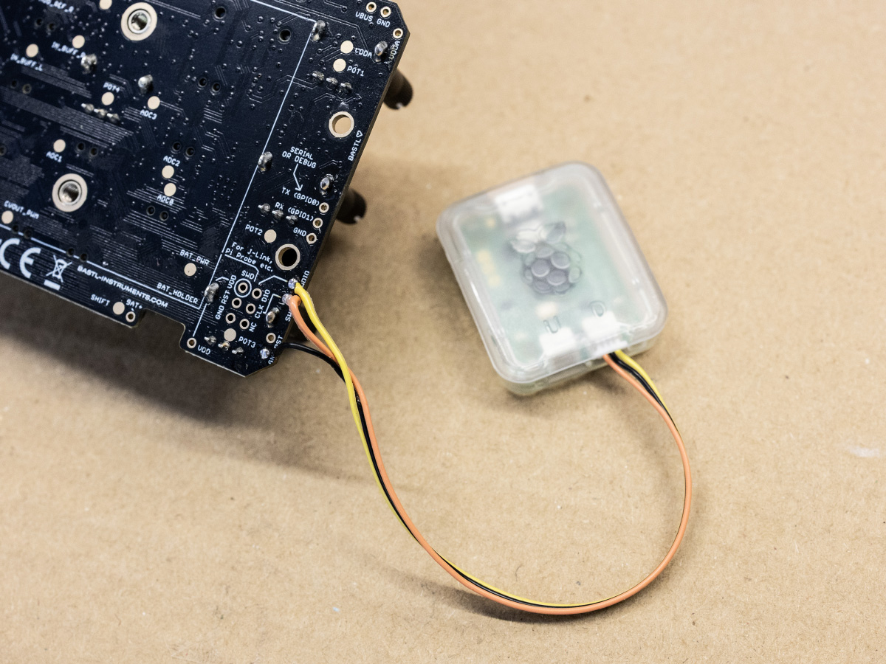
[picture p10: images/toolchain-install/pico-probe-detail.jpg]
Pico Probe cable soldered to SWD pins
 

#### Run the cable under the battery holder:

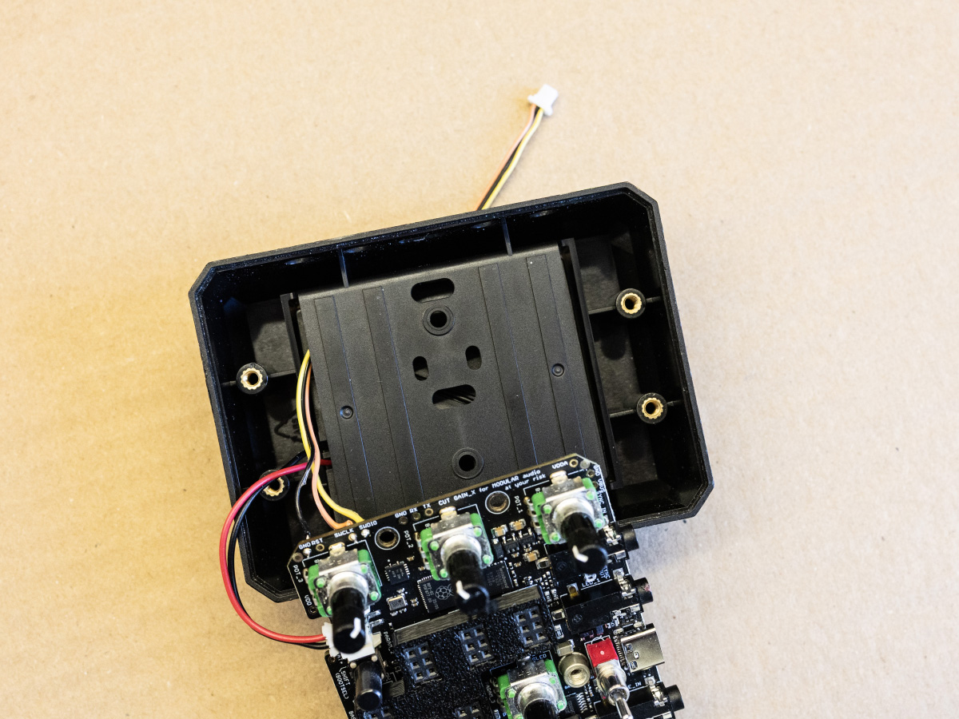
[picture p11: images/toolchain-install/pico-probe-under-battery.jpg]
Cable through battery hole
 

#### Or 3D print the provided Kastle 2 enclosure, so you can access the cable easily without drilling the original enclosure:

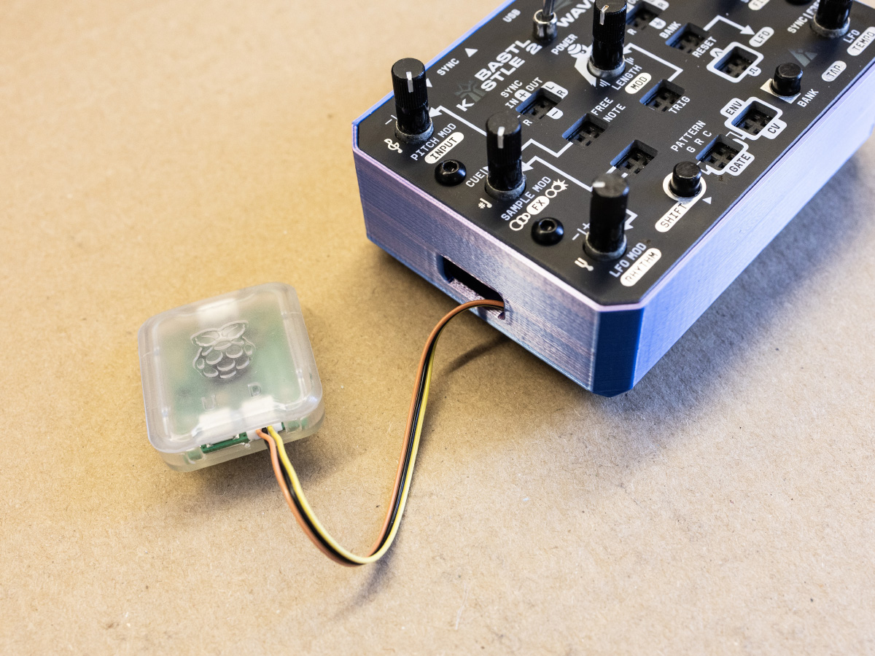
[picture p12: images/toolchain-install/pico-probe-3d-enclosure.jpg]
Custom 3D printed enclosure
 

### Citadel

For wiring the Citadel follow the instructions at the [Citadel README file](https://github.com/bastl-instruments/citadel/blob/main/README.md).

### VS Code
Make sure you have [Cortex Debug](https://marketplace.visualstudio.com/items?itemName=marus25.cortex-debug) extension installed. Go to `Run and Debug` section and select `J-Link Debug` or `Pico Probe` according to which of debug probes you have. Starting the debug process automatically builds the code and uploads it to the Kastle 2.

## Docs

The generated documentation is hosted here: [Kastle 2 Code Documentation](http://apps.bastl-instruments.com/kastle2-docs)

For building your own, run VS Code command `make_docs` or cd manually into `code` folder and run `doxygen` command.

The docs are located in `code/docs/output` and are in gitignore to keep the repository clean.

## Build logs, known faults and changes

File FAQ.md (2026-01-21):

# FAQ

## Can I buy a Kastle 2 or Citadel kit?

Yes! Kits are available from the [official Bastl shop](http://shop.bastl-instruments.com).

## Will you update to RP2350?

All development and testing for Kastle 2 was completed using the RP2040, and production began before the RP2350 was announced. While the RP2350 offers more power, its pinout and compiled binaries are not directly compatible with the RP2040. To keep the Kastle 2 family unified, we chose to stick with the RP2040—a reliable, well-known chip that delivers good enough performance for Kastle 2. Of course, you’re welcome to create your own Kastle 2 derivative using newer hardware if you wish!

## Will you release Alchemist as Open Source?

Right now we don’t plan to release the Alchemist source code to the public, since it’s packed with a lot of Bastl’s secret sauce that we might use in future projects.

## Can you share the board/gerber/case/panel files?

As a small company, Bastl Instruments relies on manufacturing and selling assembled units and kits. We’ve open-sourced the schematics, but the board design remains proprietary to help prevent straightforward product copying. We encourage you to develop your own designs and improvements, rather than simply duplicating the original.

The same applies to panel and case files: we provide general outlines and blank templates so you can create your own unique Kastle 2.

If you make Kastle 2-derived instruments, please remember to follow the license terms described in the [README](README.md).

## How to contribute to the Kastle 2?

See the [CONTRIBUTING](CONTRIBUTING.md) file.

## The compiler says...

### Undefined reference.
Make sure you added the *.cpp file to CmakeLists.txt

### tusb.h: No such file or directory
You probably don't have Pico SDK GIT submodules initialized.
Go to the Pico SDK directory and call:
```
git submodule init
git submodule update
```
Then you have to configure cmake again, by running VS Code task **Configure** or manually.

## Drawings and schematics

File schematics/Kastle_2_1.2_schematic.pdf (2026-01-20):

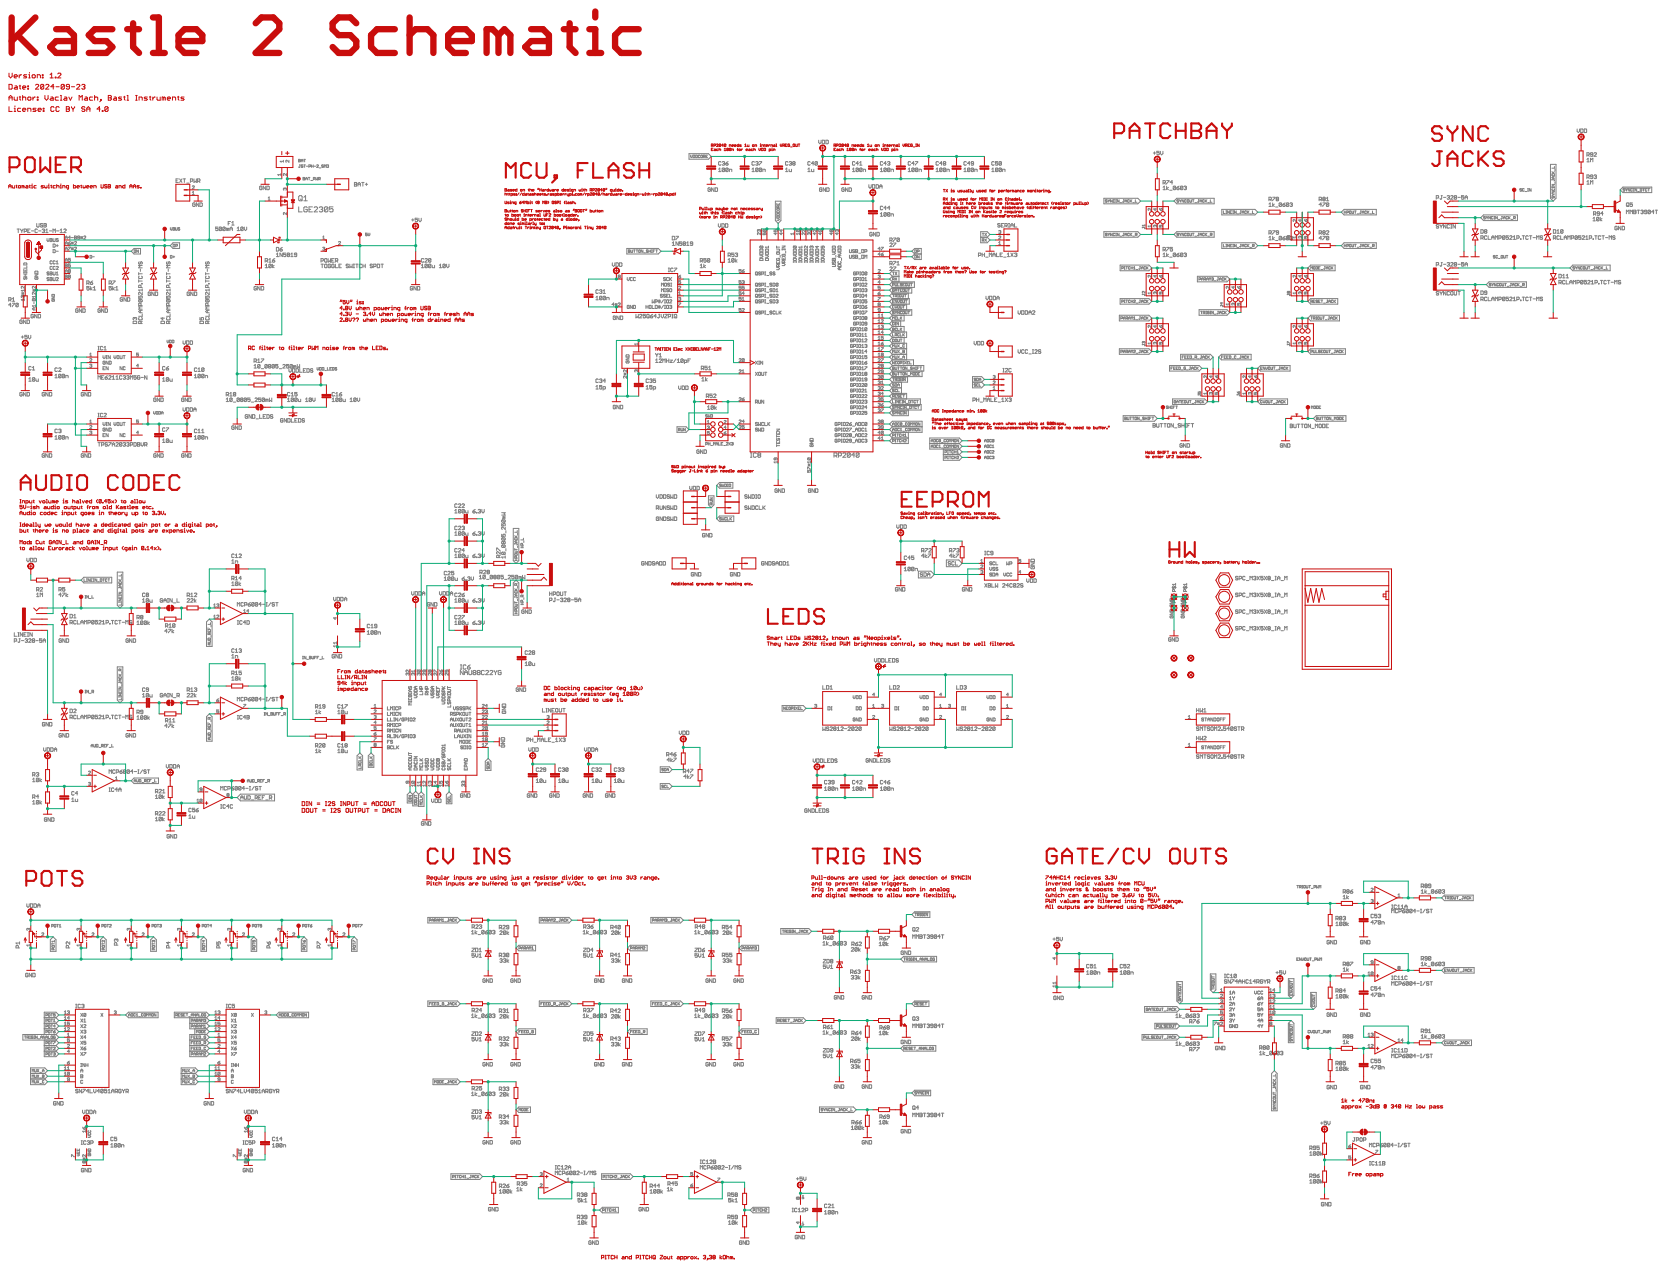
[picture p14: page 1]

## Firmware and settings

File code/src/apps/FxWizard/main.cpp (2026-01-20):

/*
MIT License

Copyright (c) 2023 Vaclav Mach (Bastl Instruments)
Copyright (c) 2023 Marek Mach (Bastl Instruments)

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
THE SOFTWARE IS PROVIDED "AS IS", WITHOUT WARRANTY OF ANY KIND, EXPRESS OR
IMPLIED, INCLUDING BUT NOT LIMITED TO THE WARRANTIES OF MERCHANTABILITY,
FITNESS FOR A PARTICULAR PURPOSE AND NONINFRINGEMENT. IN NO EVENT SHALL THE
AUTHORS OR COPYRIGHT HOLDERS BE LIABLE FOR ANY CLAIM, DAMAGES OR OTHER
LIABILITY, WHETHER IN AN ACTION OF CONTRACT, TORT OR OTHERWISE, ARISING FROM,
OUT OF OR IN CONNECTION WITH THE SOFTWARE OR THE USE OR OTHER DEALINGS IN THE
SOFTWARE.
*/

// Main stuff
#include "common/core/Kastle2.hpp"
#include "common/testmode/VersionChainGenerator.hpp"
#include "apps/FxWizard/AppFxWizard.hpp"
#include "version_samples_app.hpp"

using namespace kastle2;

/**
 * @file main.cpp
 * @brief Main entry point for Kastle 2 firmware.
 * @author Vaclav Mach (Bastl Instruments), Marek Mach (Bastl Instruments)
 * @date 2023-11-28
 */

#define APP_VERSION "1.6"
AppFxWizard app;

static void process_audio(q15_t *input, q15_t *output, size_t size)
{
    app.AudioLoop(input, output, size);
}

static void second_core()
{
    app.SecondCoreWorker();
}

static void midi_callback(midi::Message *msg)
{
    app.MidiCallback(msg);
}

int main()
{
    // Initializes the hardware, passing the version chain
    Kastle2::Init(VersionChainGenerator::Generate(version::fx_wizard, APP_VERSION));

    // Register it with the Kastle 2
    // Clears the EEPROM app space if the ID is different
    Kastle2::RegisterApp(&app);

    // Initialize the app
    app.Init();

    // Start second core
    Kastle2::StartSecondCore(second_core);

    // Start I2S
    Kastle2::StartAudio(process_audio);

    // Set the MIDI callback
    Kastle2::SetAppMidiCallback(midi_callback);

    // Infinite program loop
    while (true)
    {
        Kastle2::ReadInputs();
        app.UiLoop();
    }

    return 0;
}

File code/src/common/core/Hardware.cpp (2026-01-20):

/*
MIT License

Copyright (c) 2024 Vaclav Mach (Bastl Instruments)

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
THE SOFTWARE IS PROVIDED "AS IS", WITHOUT WARRANTY OF ANY KIND, EXPRESS OR
IMPLIED, INCLUDING BUT NOT LIMITED TO THE WARRANTIES OF MERCHANTABILITY,
FITNESS FOR A PARTICULAR PURPOSE AND NONINFRINGEMENT. IN NO EVENT SHALL THE
AUTHORS OR COPYRIGHT HOLDERS BE LIABLE FOR ANY CLAIM, DAMAGES OR OTHER
LIABILITY, WHETHER IN AN ACTION OF CONTRACT, TORT OR OTHERWISE, ARISING FROM,
OUT OF OR IN CONNECTION WITH THE SOFTWARE OR THE USE OR OTHER DEALINGS IN THE
SOFTWARE.
*/

#include <cstddef>
#include <cstdint>

#include "pico/stdlib.h"
#include "hardware/adc.h"
#include "hardware/i2c.h"
#include "hardware/irq.h"
#include "hardware/pwm.h"
#include "hardware/sync.h"

#include "common/core/Kastle2.hpp"
#include "common/debug.hpp"
#include "common/dsp/math/math_utils.hpp"
#include "common/peripherals/WS2812.hpp"
#include "common/utils.hpp"

#include "Hardware.hpp"

using namespace kastle2;

WS2812 pixels = WS2812(Hardware::PIN_LEDS, 3, pio0, 3);

EnumArray<Hardware::Button, size_t> ButtonsPins = {
    Hardware::PIN_BUTTON_SHIFT,
    Hardware::PIN_BUTTON_MODE};

EnumArray<Hardware::DigitalInput, size_t> DigitalInputsPins = {
    Hardware::PIN_TRIG_IN,
    Hardware::PIN_RESET_IN,
    Hardware::PIN_SYNC_IN,
    Hardware::PIN_AUDIO_IN_DETECT,
    Hardware::PIN_SYNC_IN_DETECT};

EnumArray<Hardware::Pot, Hardware::AnalogInput> PotToAnalogInputMap = {
    Hardware::AnalogInput::POT_1,
    Hardware::AnalogInput::POT_2,
    Hardware::AnalogInput::POT_3,
    Hardware::AnalogInput::POT_4,
    Hardware::AnalogInput::POT_5,
    Hardware::AnalogInput::POT_6,
    Hardware::AnalogInput::POT_7};

// Hardware class instance for ADC interrupt handler
static Hardware *hardware_instance = nullptr;

// ADC interrupt handler
static void adc_irq_handler()
{
    if (hardware_instance != nullptr)
    {
        hardware_instance->AdcIrqHandler();
    }
}

void Hardware::Init()
{
    // Set handler access to this instance
    hardware_instance = this;

    // Detect whether Kastle 2 or Citadel
    ReadVersion();

    // Set panel type (so the LEDs are displayed correctly)
    panel_type_ = PanelType::DEFAULT_GREY;

    // Update calibrations
    for (Calibration c : EnumRange<Calibration>())
    {
        custom_calibrations_[c] = 0; // Initialize custom calibrations to 0
    }
    UpdateCalibrationMaps();

    // Init I2C
    i2c_init(I2C_INSTANCE, 100 * 1000); // 100 kHz
    gpio_set_pulls(PIN_SDA, true, false);
    gpio_set_pulls(PIN_SCL, true, false);
    gpio_set_function(PIN_SDA, GPIO_FUNC_I2C);
    gpio_set_function(PIN_SCL, GPIO_FUNC_I2C);
    gpio_set_drive_strength(PIN_SDA, GPIO_DRIVE_STRENGTH_8MA);
    gpio_set_drive_strength(PIN_SCL, GPIO_DRIVE_STRENGTH_8MA);

    // Init I2S driver
    i2s_.Init(
        SAMPLE_RATE,
        {
            .mclk = PIN_MCLK,
            .dout = PIN_DOUT,
            .din = PIN_DIN,
            .bclk = PIN_BCLK,
        });

    // Init TX & RX pin
    gpio_init(PIN_TX);
    gpio_set_dir(PIN_TX, GPIO_OUT);

#if !DEBUG_TWO_USING_RX
    gpio_init(PIN_RX);
    gpio_set_dir(PIN_RX, GPIO_IN);
    // RP2040 has pull down by default, we need to turn it off
    gpio_set_pulls(PIN_RX, false, false);
#else
    gpio_init(PIN_RX);
    gpio_set_dir(PIN_RX, GPIO_OUT);
#endif

    // Init NeoPixels
    for (Led led : EnumRange<Led>())
    {
        pixels.SetPixelColor(static_cast<size_t>(led), 0x000000);
    }
    pixels.Show();

    // Inits ADCs
    gpio_init(PIN_MUX_A);
    gpio_set_dir(PIN_MUX_A, GPIO_OUT);
    gpio_init(PIN_MUX_B);
    gpio_set_dir(PIN_MUX_B, GPIO_OUT);
    gpio_init(PIN_MUX_C);
    gpio_set_dir(PIN_MUX_C, GPIO_OUT);
    adc_init();

    adc_gpio_init(26);
    adc_gpio_init(27);
    adc_gpio_init(28);
    adc_gpio_init(29);
    adc_values_.fill(0);
    adc_dirty_counter_.fill(0);

    // Enable ADC FIFO and interrupts
    adc_fifo_setup(
        true,  // Write each result to the FIFO
        false, // Enable DMA data request (not used here)
        1,     // DREQ at least 1 sample in FIFO
        false, // No ERR bit
        false  // Shift 12-bit to 8-bit (we want full 12-bit)
    );

    // Enable ADC IRQ and set handler
    irq_set_exclusive_handler(ADC_IRQ_FIFO, adc_irq_handler);
    irq_set_enabled(ADC_IRQ_FIFO, true);
    adc_irq_set_enabled(true);

    // Start first conversion
    StartAdcConversion();

    // Init buttons
    for (Button b : EnumRange<Button>())
    {
        size_t pin = ButtonsPins[b];
        gpio_init(pin);
        gpio_set_dir(pin, GPIO_IN);
        gpio_set_pulls(pin, true, false);
    }

    buttons_just_pressed_.fill(false);
    buttons_just_released_.fill(false);
    prev_buttons_pressed_.fill(false);
    buttons_pressed_.fill(false);
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

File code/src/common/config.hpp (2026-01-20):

/*
MIT License

Copyright (c) 2024 Vaclav Mach (Bastl Instruments)

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
THE SOFTWARE IS PROVIDED "AS IS", WITHOUT WARRANTY OF ANY KIND, EXPRESS OR
IMPLIED, INCLUDING BUT NOT LIMITED TO THE WARRANTIES OF MERCHANTABILITY,
FITNESS FOR A PARTICULAR PURPOSE AND NONINFRINGEMENT. IN NO EVENT SHALL THE
AUTHORS OR COPYRIGHT HOLDERS BE LIABLE FOR ANY CLAIM, DAMAGES OR OTHER
LIABILITY, WHETHER IN AN ACTION OF CONTRACT, TORT OR OTHERWISE, ARISING FROM,
OUT OF OR IN CONNECTION WITH THE SOFTWARE OR THE USE OR OTHER DEALINGS IN THE
SOFTWARE.
*/

#pragma once

#include "pico/stdlib.h"
#include "I2S.hpp"

/**
 * @file config.hpp
 * @ingroup core
 * @brief Core project configuration and constants.
 * @author Vaclav Mach (Bastl Instruments)
 * @date 2024-03-27
 */

namespace kastle2
{

/**
 * Kastle 2's 8MB memory is divided into 2 sections:
 * 512 KB for the main code
 * 7.5 MB for the user data (eg. samples)
 */
#define USER_DATA_SECTION __attribute__((section(".user_data")))
#define USER_DATA_SECTION_BEGIN 0x10080000 // at 512 KB

/**
 * Close to 44100 - "weird" frequency, because we need the RP2040 to run at
 * a multiplied frequency and frequencies of RP2040 are limited
 * (need to be calculated by rp2040_freq.py in scrpts folder and confirmed by vcocalc.py in Pico SDK).
 */
static constexpr float SAMPLE_RATE = 44000.0f;

/**
 * Seconds to sample rate samples (s * SAMPLE_RATE)
 * @param s Seconds to convert
 * @return Number of samples in SAMPLE_RATE (44000 Hz)
 */
static consteval size_t s2sr(float s)
{
    return static_cast<size_t>(s * SAMPLE_RATE);
}

/**
 * Audio buffer frames for Kastle 2 in stereo
 * Actually is 96 "real" frames (2*48 frames)
 */
static constexpr size_t AUDIO_BUFFER_SIZE = I2S::kAudioBufferSize;

/**
 * Basically SAMPLE_RATE / buffer size (48)
 */
static constexpr float AUDIO_LOOP_RATE = SAMPLE_RATE / static_cast<float>(AUDIO_BUFFER_SIZE);

/**
 * Seconds to audio loop rate samples (s * AUDIO_LOOP_RATE)
 * @param s Seconds to convert
 * @return Number of samples in AUDIO_LOOP_RATE (916 Hz)
 */
static consteval size_t s2alr(float s)
{
    return static_cast<size_t>(s * AUDIO_LOOP_RATE);
}

/**
 * Converts Hz to audio loop rate samples
 * @param hz Frequency in Hz to convert
 * @return Number of samples in AUDIO_LOOP_RATE (916 Hz)
 */
static consteval size_t hz2alr(float hz)
{
    return static_cast<size_t>(AUDIO_LOOP_RATE / hz);
}

/**
 * Because SYSTEM_CLOCK_KHZ / SAMPLE_RATE needs to be round number
 * Slightly overclocked (base is 133 MHz), but should be all right
 */
static constexpr uint32_t SYSTEM_CLOCK_KHZ = 176000;

/**
 * Max value of the DAC output (PWM-based, filtered)
 */
static constexpr int32_t DAC_MAX = 1023;

/**
 * ADC values for standard voltages
 * On Kastle 2 default the ADC values are 0-4095,
 * but in Citadel it's scaled to -4095 to 4095 since the inputs are bipolar.
 */
static constexpr int32_t ADC_0V = 0;
static constexpr int32_t ADC_1V = 819;
static constexpr int32_t ADC_2V = 2 * ADC_1V;
static constexpr int32_t ADC_3V = 3 * ADC_1V;
static constexpr int32_t ADC_4V = 4 * ADC_1V;
static constexpr int32_t ADC_5V = 5 * ADC_1V;
static constexpr int32_t ADC_6V = 6 * ADC_1V;
static constexpr int32_t ADC_7V = 7 * ADC_1V;
static constexpr int32_t ADC_8V = 8 * ADC_1V;
static constexpr int32_t ADC_N1V = -1 * ADC_1V;
static constexpr int32_t ADC_N2V = -2 * ADC_1V;
static constexpr int32_t ADC_N3V = -3 * ADC_1V;
static constexpr int32_t ADC_N4V = -4 * ADC_1V;
static constexpr int32_t ADC_N5V = -5 * ADC_1V;

static constexpr int32_t ADC_N02V = -164;

/**
 * DAC values for 0V, 1V, 2V, 3V, 4V
 * Rough estimations, for USB powered (5.0V)
 */
static constexpr int32_t DAC_0V = 0;
static constexpr int32_t DAC_1V = 220;
static constexpr int32_t DAC_2V = 440;
static constexpr int32_t DAC_3V = 660;
static constexpr int32_t DAC_4V = 878;

/**
 * POT VALUES
 * Regular 12-bit ADC values (0-4095)
 */
static constexpr int32_t POT_MIN = 0;
static constexpr int32_t POT_MAX = 4095;
static constexpr int32_t POT_THIRD = (POT_MAX / 3);
static constexpr int32_t POT_HALF = (POT_MAX / 2);
static constexpr int32_t POT_TWO_THIRDS = (POT_MAX * 2 / 3);
static constexpr int32_t POT_MOVE_THRESHOLD = 48;
static constexpr int32_t POT_RANGE = 4096;

} // namespace kastle2

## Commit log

2026-01-20 Initial open-source release of Kastle 2
    [kastle2-case-nographics-noinserts-programming.stl, kastle2-case-nographics-noinserts.stl, kastle2-case-nographics-programming.stl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]
2026-01-23 Add a note about samples
2026-08-14 Indicate root and scale change only when holding BANK button
